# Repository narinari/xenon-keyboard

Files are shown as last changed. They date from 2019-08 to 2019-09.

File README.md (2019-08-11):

# xenon-keyboard
Xenon is 60% columnar staggered keyboard.

## xenon-classic

Full feature version Xenon
- Cherry MX and Kailh low profile key switch support
- OLED display
- Full color LED
- Prototype board area (behind the promicro)

Xenon with Godspeed custom SA keycap
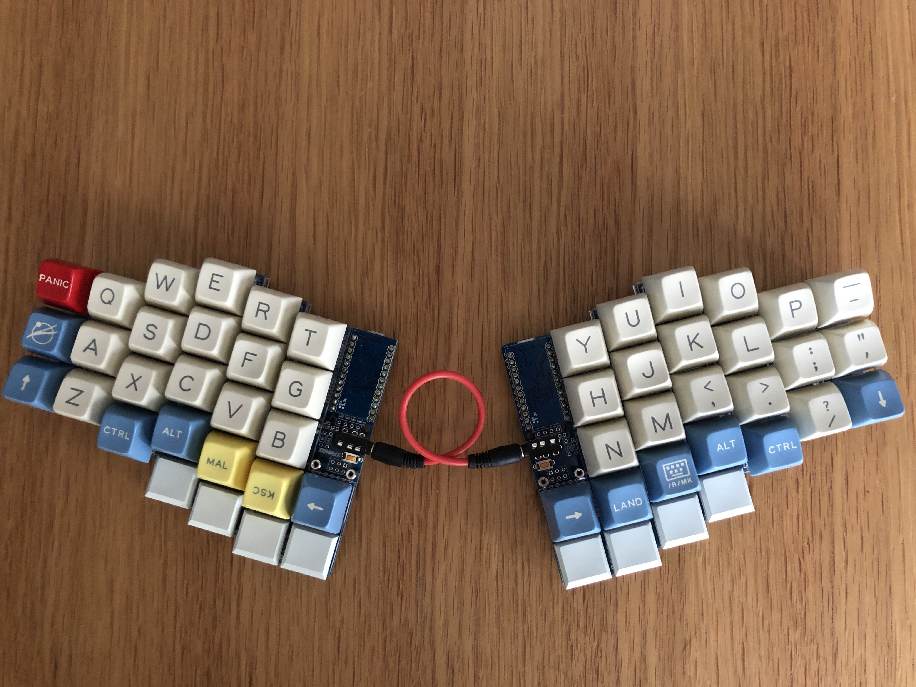
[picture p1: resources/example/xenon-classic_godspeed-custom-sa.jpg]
Xenon with Godspeed custom SA keycap


Xenon with MiTo GMK Laser custom keycap
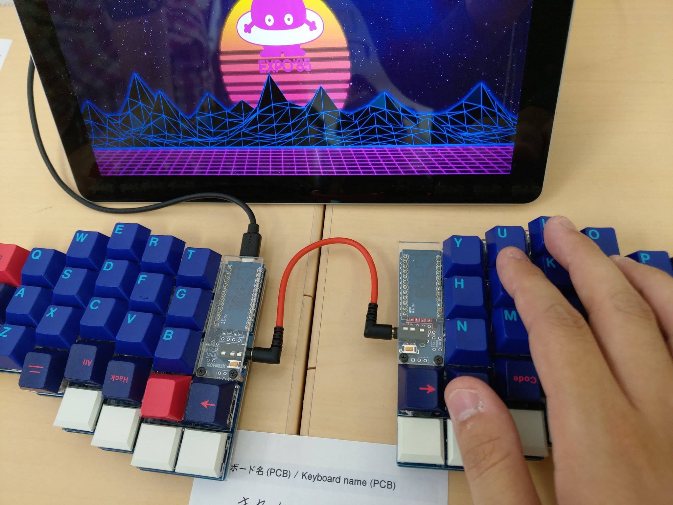
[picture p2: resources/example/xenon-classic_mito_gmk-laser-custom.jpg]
Xenon with MiTo GMK Laser custom keycap


Xenon with MDA BigBang and 3D printed keycap
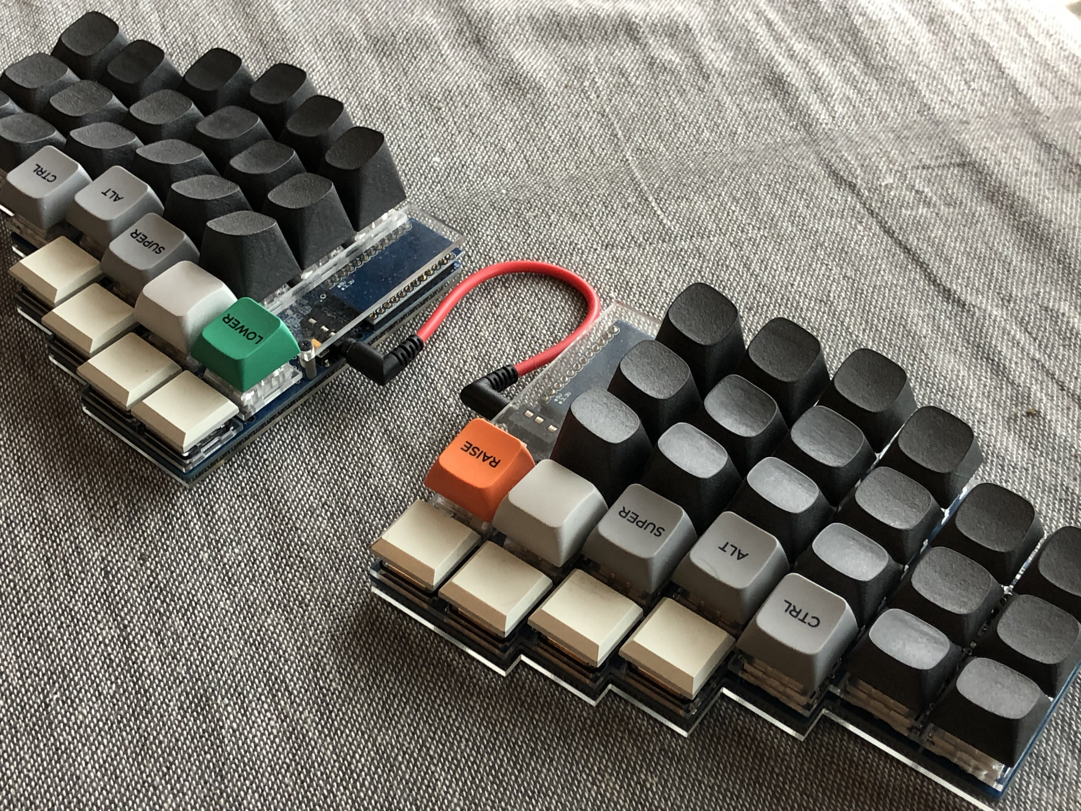
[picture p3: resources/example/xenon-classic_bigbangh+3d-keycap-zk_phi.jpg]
Xenon with MDA BigBang and 3D printed keycap


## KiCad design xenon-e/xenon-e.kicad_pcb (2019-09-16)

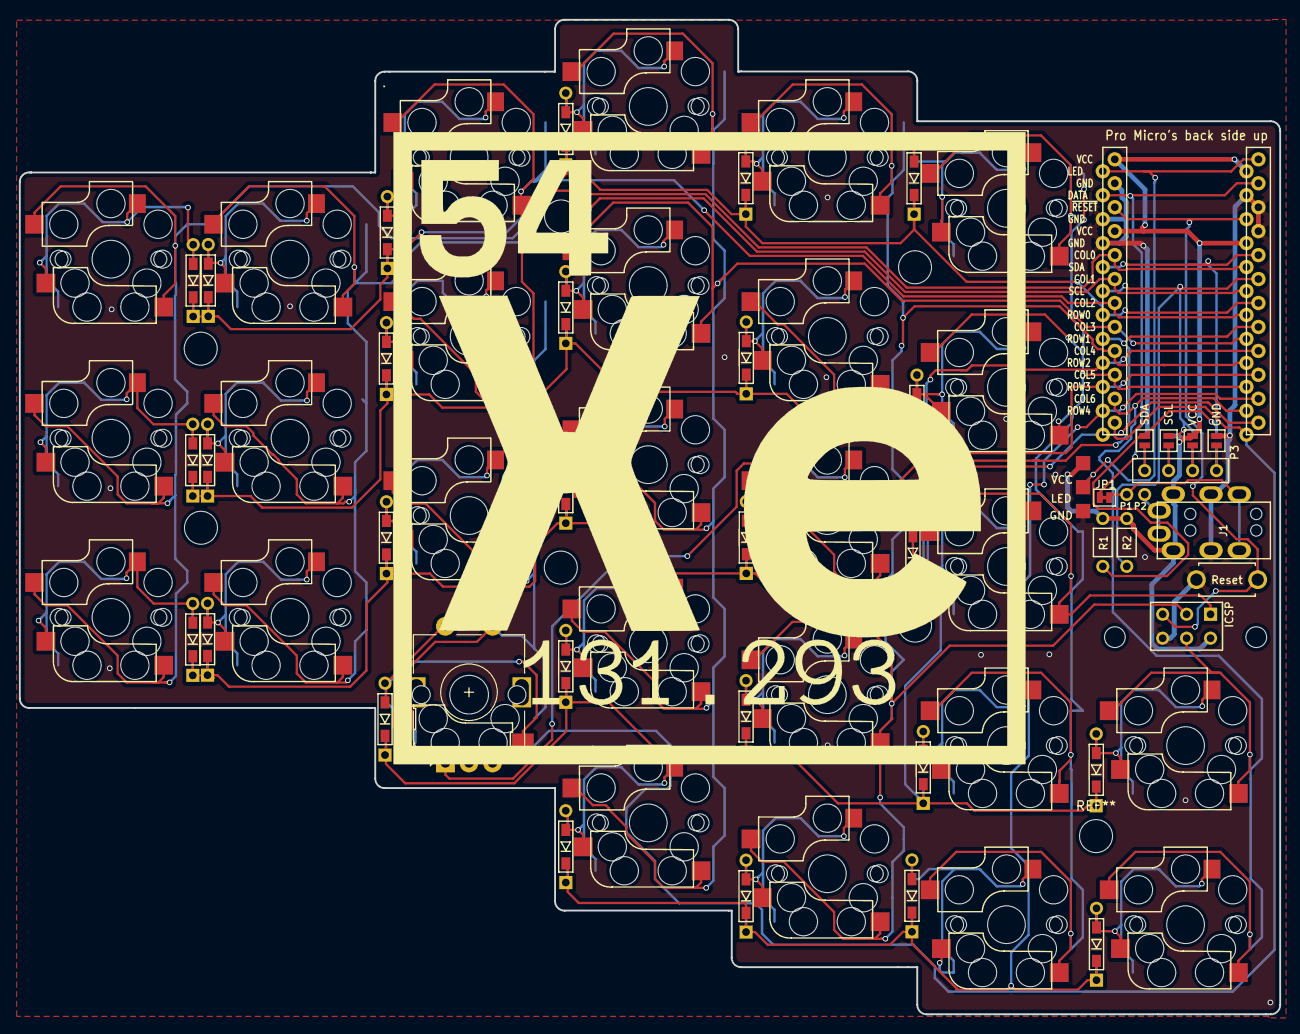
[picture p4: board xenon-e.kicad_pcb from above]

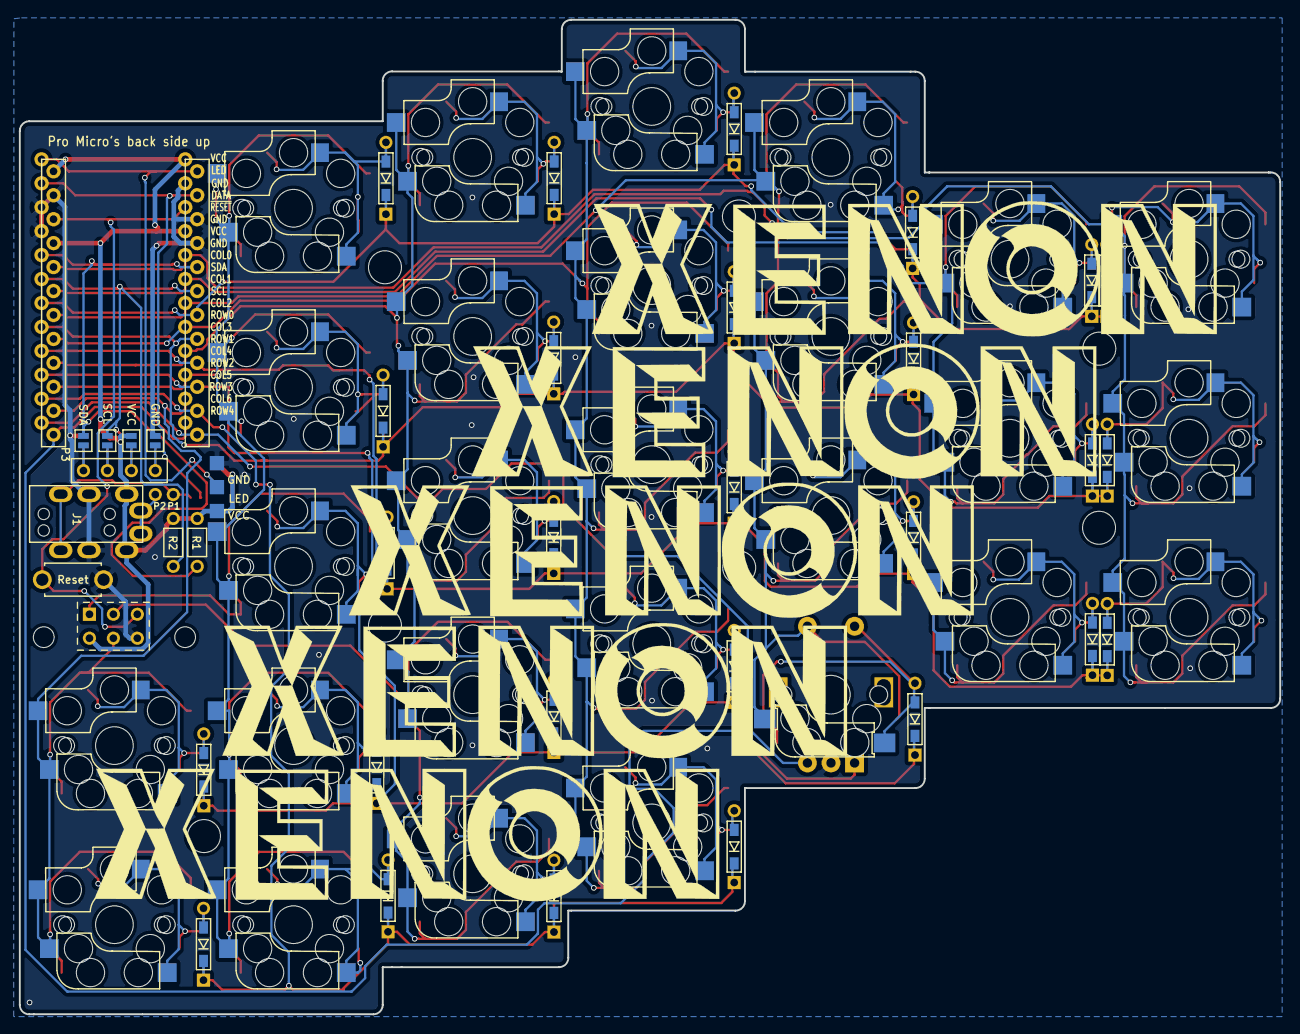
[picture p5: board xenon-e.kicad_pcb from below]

Board: 2 copper layers, 133.7 x 105.5 mm, 81 parts (5 on the bottom side), 54 nets.

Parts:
D1, D2, D3, D4, D5, D6, D7, D8, D9, D10, D11, D12, D13, D14, D15, D16, D17, D18, D21, D22, D23, D24, D25, D29, D30, D31, D32: D; D3_TH_SMD
J1: MJ-4PP-9; MJ-4PP-9_rev2
JP1: JPC2
JP4, JP11: GND; Jumper
JP5, JP10: VCC; Jumper
JP6, JP9: SCL; Jumper
JP7, JP8: SDA; Jumper
P1, P2: CONN_01X01; 1PIN_0.1
P3: OLED; MY_SIL-4
P4: LED; StripLED_rev
P5: ICSP; MY_SIL-2x3
R1, R2: R; R2
Ref**: Val**; MountingHole_3.5mm
Ref**#2, Ref**#3, Ref**#4, Ref**#5, Ref**#6: Val**; MountingHole_3.5mm
SW1, SW2, SW3, SW4, SW5, SW6, SW7, SW8, SW9, SW10, SW11, SW12, SW13, SW14, SW15, SW16, SW17, SW18, SW22, SW23, SW24, SW25, SW29, SW30, SW31, SW32: SW_PUSH; CherryMX_Choc_Hotswap
SW21: SW_PUSH; CherryMX_Hotswap
SW33: Reset; SW_3.5x6.0_TH
SW34: Rotary_Encoder_Switch; RotaryEncoder_Alps_EC11E-Switch_Vertical_H20mm
U1, U1#2: ProMicro; ProMicro_rev

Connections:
/SCL: JP6.1, JP9.1, R2.2, U1.6, U1#2.6
/SDA: JP7.1, JP8.1, R1.2, U1.5, U1#2.5
/~RESET: P5.5, SW33.2, U1.22, U1#2.22
GND: J1.C, JP4.1, JP11.1, P4.3, P5.6, SW33.1, SW34.C, U1.3, U1.4, U1.23, U1#2.3, U1#2.4, U1#2.23
LED: P4.2, U1.1, U1#2.1
unnamed: D1.2, SW1.2
unnamed: D2.2, SW2.2
unnamed: D3.2, SW3.2
unnamed: D4.2, SW4.2
unnamed: D5.2, SW5.2
unnamed: D6.2, SW6.2
unnamed: D7.2, SW7.2
unnamed: D8.2, SW8.2
unnamed: D9.2, SW9.2
unnamed: D10.2, SW10.2
unnamed: D11.2, SW11.2
unnamed: D12.2, SW12.2
unnamed: D13.2, SW13.2
unnamed: D14.2, SW14.2
unnamed: D15.2, SW15.2
unnamed: D16.2, SW16.2
unnamed: D17.2, SW17.2
unnamed: D18.2, SW18.2
unnamed: D21.2, SW21.2, SW34.S2
unnamed: D22.2, SW22.2
unnamed: D23.2, SW23.2
unnamed: D24.2, SW24.2
unnamed: D25.2, SW25.2
unnamed: D29.2, SW29.2
unnamed: D30.2, SW30.2
unnamed: D31.2, SW31.2
unnamed: D32.2, SW32.2
unnamed: J1.A, P2.1
unnamed: J1.B, JP1.2, P1.1
unnamed: JP4.2, JP8.2, P3.1
unnamed: JP5.2, JP9.2, P3.2
unnamed: JP6.2, JP10.2, P3.3
unnamed: JP7.2, JP11.2, P3.4
ROTARY_A: SW34.A, U1.12, U1#2.12
ROTARY_B: SW34.B, U1.13, U1#2.13
VCC: J1.D, JP5.1, JP10.1, P4.1, P5.2, R1.1, R2.1, U1.21, U1.24, U1#2.21, U1#2.24
col0: SW1.1, SW7.1, SW13.1, U1.20, U1#2.20
col1: SW2.1, SW8.1, SW14.1, U1.19, U1#2.19
col2: SW3.1, SW9.1, SW15.1, SW21.1, SW34.S1, U1.18, U1#2.18
col3: SW4.1, SW10.1, SW16.1, SW22.1, SW29.1, U1.17, U1#2.17
col4: P5.3, SW5.1, SW11.1, SW17.1, SW23.1, SW30.1, U1.16, U1#2.16
col5: P5.1, SW6.1, SW12.1, SW18.1, SW24.1, SW31.1, U1.15, U1#2.15
col6: P5.4, SW25.1, SW32.1, U1.14, U1#2.14
data: JP1.1, U1.2, U1#2.2
row0: D1.1, D2.1, D3.1, D4.1, D5.1, D6.1, U1.7, U1#2.7
row1: D7.1, D8.1, D9.1, D10.1, D11.1, D12.1, U1.8, U1#2.8
row2: D13.1, D14.1, D15.1, D16.1, D17.1, D18.1, U1.9, U1#2.9
row3: D21.1, D22.1, D23.1, D24.1, D25.1, U1.10, U1#2.10
row4: D29.1, D30.1, D31.1, D32.1, U1.11, U1#2.11

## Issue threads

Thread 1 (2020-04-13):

HEX/Keymap for the Xenon?

Kyrremann, 2020-04-13:
I've ordered my own Xenon, and started building it, but can't find the keymap for it. Have you made one to share, or should I create my own?

Also, have you thought about making a build guide? I'm taking pictures while I'm building it, but don't have the best camera setup for a proper guide.

Kyrremann, 2020-05-01:
I've made my own now, and I'll soon create a PR for qmk, just need to test the OLED
https://github.com/Kyrremann/qmk_firmware/tree/xenon/keyboards/xenon

All credits to you, but used my name in the license, as it felt strange to put your name there without your acknowledge. Let me know what you'd like.

molohov, 2021-11-18:
> I've made my own now, and I'll soon create a PR for qmk, just need to test the OLED https://github.com/Kyrremann/qmk_firmware/tree/xenon/keyboards/xenon
>
> All credits to you, but used my name in the license, as it felt strange to put your name there without your acknowledge. Let me know what you'd like.

Thank your for sharing this!

ifohancroft, 2022-01-31:
Sorry to hijack the issue but where's the OLED on the keyboard? I can't see it on any of the pictures.

Kyrremann, 2022-01-31:
It's right over the Pro Micro, but it's in none of the pictures. Similar style as [Corne](https://github.com/foostan/crkbd).

ifohancroft, 2022-02-01:
Thank you!

ifohancroft, 2022-02-03:
Can you tell me what model OLED screen supports so I can buy it for my Xenon?
Also the readme says it supports full color LEDs - I presume this means RGB? However, is it underglow or is it per key? Any specific model? I couldn't figure it out looking at the KiCad files as the schematic symbols library is missing from the repo

Kyrremann, 2022-02-03:
About the OLED, you can read the technical know-how over at [QMK](https://docs.qmk.fm/#/feature_oled_driver). The short answer is any OLED that support SSD1306 or SH1106, and fits the case.

You should find them if you search for 0.91 inch OLED. They look like this:
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

Not sure about the LEDS, I see that there is support for LED-strips, so my guess is that's all there is.

ifohancroft, 2022-02-03:
Thank you!
Do you happen to know if the acrylic cover comes with the OLED module or what are its dimensions?

The case, I presume is just the bottom plate and you mount the plate, pcb and bottom plate? Also what size standoffs?

I got gifted the Xenon with everything (including keycaps and switches) but there is no bottom plate and the repo doesn't include a build guide.

Kyrremann, 2022-02-03:
You have to cut your own OLED acrylic cover, bottom plate, and switch plate. I used this file to do it: https://github.com/narinari/xenon-keyboard/blob/master/xenon-e/cad-data/xenon-e_plate.svg
I think I use regular 8mm stand-offs, but it may be 6mm.

It sounds like your missing the case (not really necessary to use it), screws, standoffs/spacers, OLED, Pro Micro, TRRS-cable between the splits, and a usb-micro cable (for the Pro Micro).

ifohancroft, 2022-02-03:
Thank you!

When you say case? Do you mean the bottom plate?

This is what I'm actually missing. I didn't clarify well: Case (or bottom plate, not sure if they are the same thing or if there is an actual case that is different from the bottom plate), screws, standoffs/spacers, OLED, TRRS-cable and USB cable.

I have: PCBs, Switch plates, Pro Micros (with USB-C), Hotswap sockets, diodes, rotary encoders, rotary encoder caps, switches, choch switches, keycaps and chock keycaps.

Kyrremann, 2022-02-03:
When I said case I meant all the acrylic, but sounds like you are only missing a bottom plate. Not really necessary, but nice to have.

I sued 2mm acrylic for bottom plate and OLED cover. And used 10mm standoff to screw it on. It's not currently set up like that, but I can try to take a picture later today.
It's identical to this: https://github.com/foostan/crkbd/blob/main/corne-classic/doc/buildguide_en.md#oled-module

Are the USB-C Pro Micros Elite-C?

ifohancroft, 2022-02-03:
Ah! Got it. Thank you! If you can take a picture later, that would be extremely helpful.

Do you know if I need a diode on the rotary encoder? I mean if I use a rotary encoder instead of a switch below the X key on the pictures?

Honestly, I have no idea if they are Elite-C. They don't look like the Elite-C and the PCB is blue. On one side 'Pro Micro' is printed on the board. On the other 'Atmega 32u4'. I don't think they are.

Kyrremann, 2022-02-06:
The firmware is now merged into master!
https://github.com/qmk/qmk_firmware/tree/master/keyboards/xenon

Kyrremann, 2022-02-06:
I'm guessing this is the Pro Micro you https://www.sparkfun.com/products/15795 (or at least a clone of it).

Not sure if you need a diode, I soldered one there.

FR-4 cases are nice, and yeah, making it the same style as the switch plate is a good choice.

I couldn't find the OLED cover for my Xenon, but it look's just like the one for Corne.

ifohancroft, 2022-02-06:
Thank you!

Closed 2022-02-06.

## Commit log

2019-08-11 First Xenon-e pcb
    [xenon-e.kicad_pcb, xenon-e.sch]
2019-08-11 Add plate data
    [bottom-plate.kicad_pcb, bottom-plate.sch, top-plate.kicad_pcb]
2019-08-11 Add gerber files
    [xenon-e-B_Cu.gbl, xenon-e-B_Mask.gbs, xenon-e-B_SilkS.gbo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]
2019-08-11 Add gerber files of plates
    [xenon-e_plate-B_Cu.gbr, xenon-e_plate-B_Mask.gbr, xenon-e_plate-B_SilkS.gbr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]
2019-09-16 Change mouting hole size
    [top-plate.kicad_pcb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]

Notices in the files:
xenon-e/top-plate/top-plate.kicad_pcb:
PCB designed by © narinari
